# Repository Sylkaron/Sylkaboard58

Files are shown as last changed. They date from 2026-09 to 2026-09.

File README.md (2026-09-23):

# Sylkaboard58



A split ortholinear keyboard with 58 keys and two encoders for a first step in my ergonomic journey

## Table des matières
- [Overview](#-overview)
- [BOM](#️-bill-of-materials)
- [Assemblage](#-assemblage)
- [Firmware](#-firmware)
- [Layout](#-keyboard-layout)
- [Licence](#-licence)

## Overview

## BOM
 ### Keyboard

 ### Tools

## Firmware
Powered by QMK

### Requirements
- [QMK Toolbox](https://github.com/qmk/qmk_toolbox) (to flash firmware).
- [QMK Firmware](https://github.com/qmk/qmk_firmware)

### Étapes pour flasher le firmware
1. Téléchargez ou clonez le dépôt QMK :
   ```bash
   git clone https://github.com/qmk/qmk_firmware.git

## Layout

## Licence  
This project is under **[CERN OHL v2](https://ohwr.org/cern_ohl)** 
This documentation is under **[CC BY-SA 4.0](https://creativecommons.org/licenses/by-sa/4.0/)**.

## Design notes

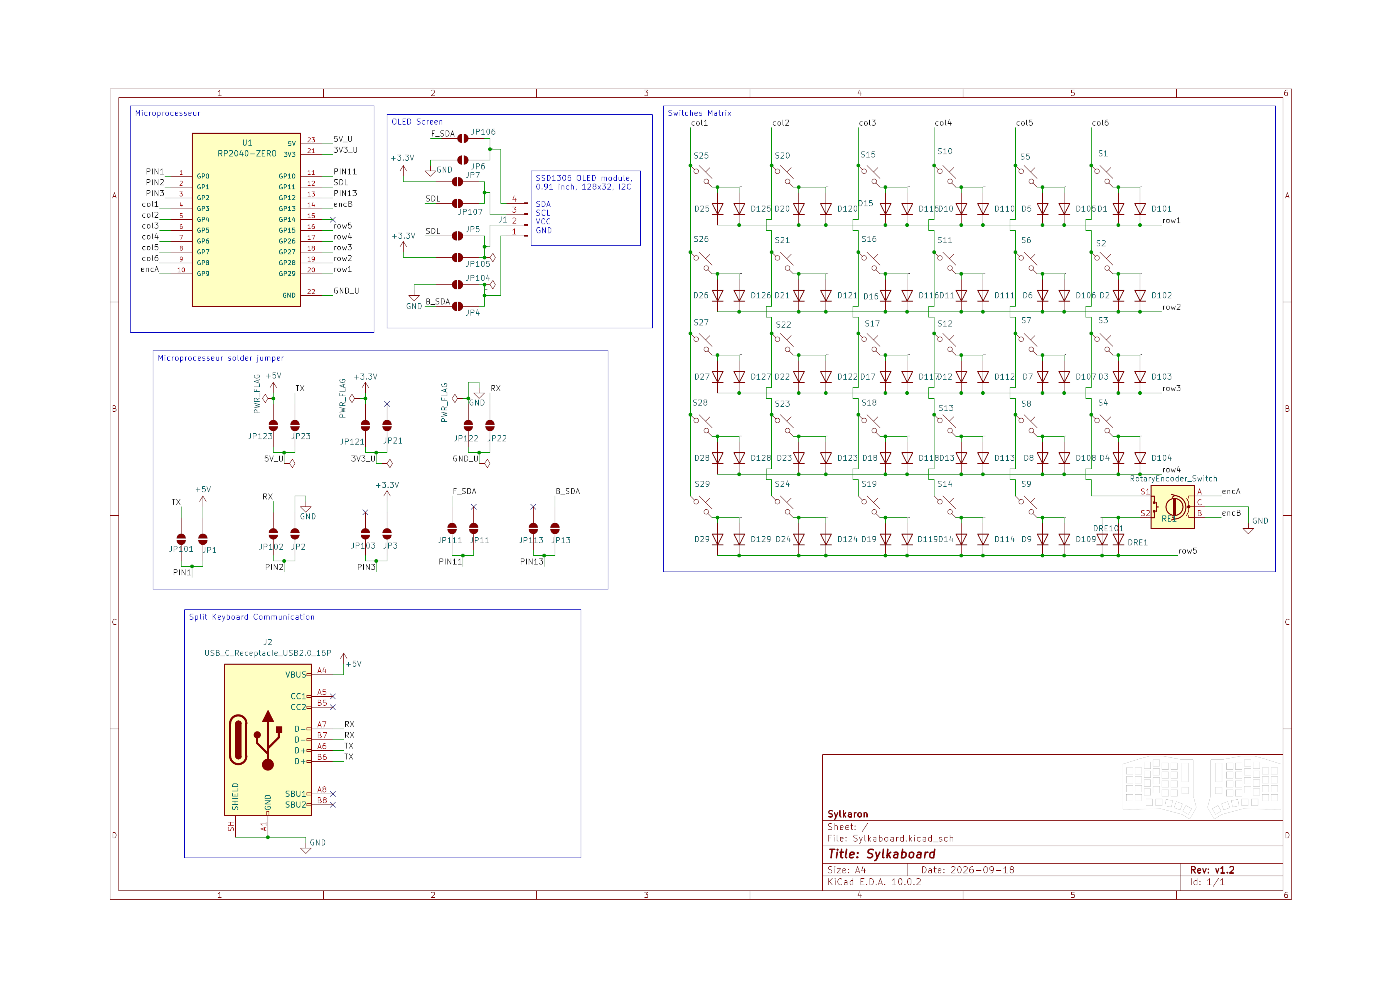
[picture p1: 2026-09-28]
Fabrications/SVG/schematic.png

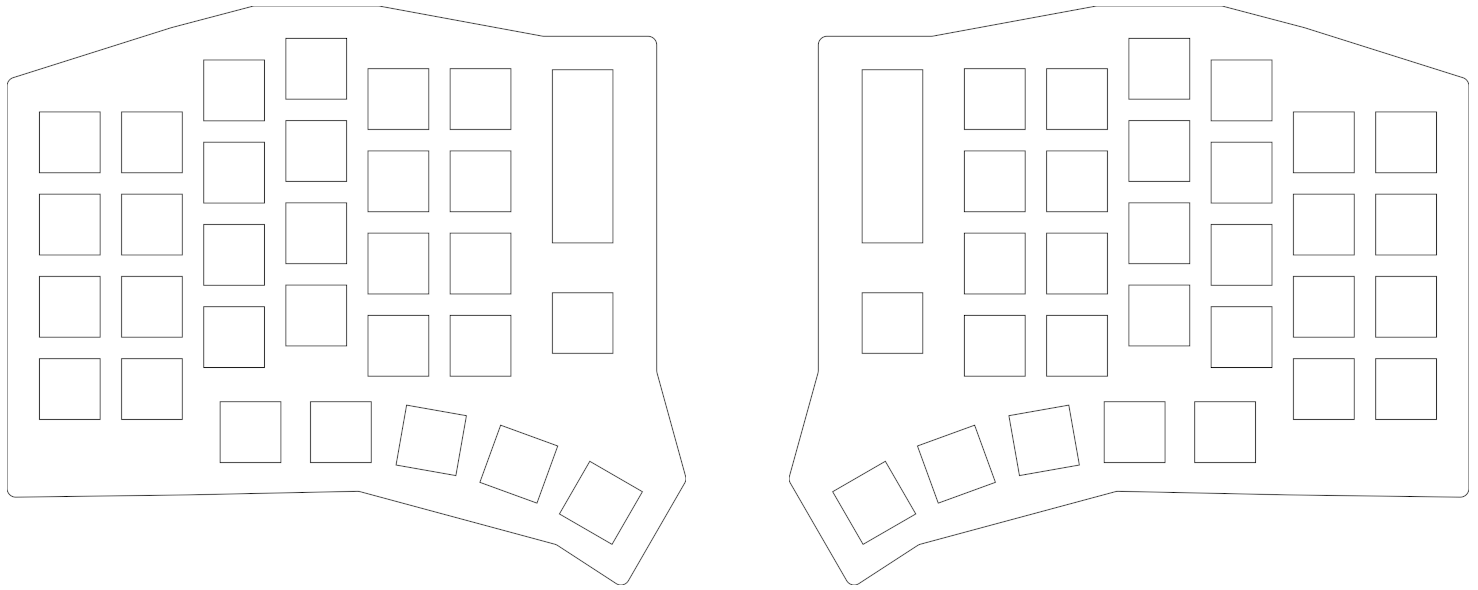
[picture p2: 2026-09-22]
Layout__definition/keyboard.png

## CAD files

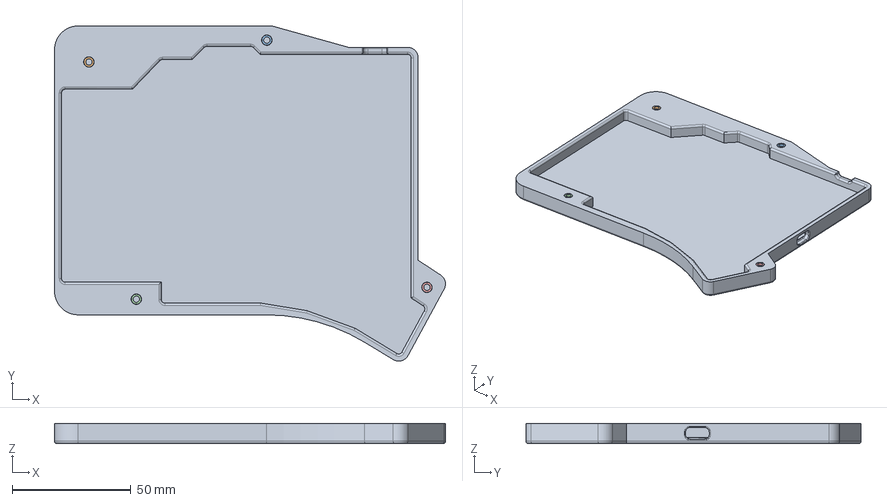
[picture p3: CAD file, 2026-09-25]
Fabrications/Case/Base_plate.FCstd
164.8 x 141.3 x 8.50 mm
Corps
M3x5.74-Insérer009
M3x5.74-Insérer
M3x5.74-Insérer012
M3x5.74-Insérer011

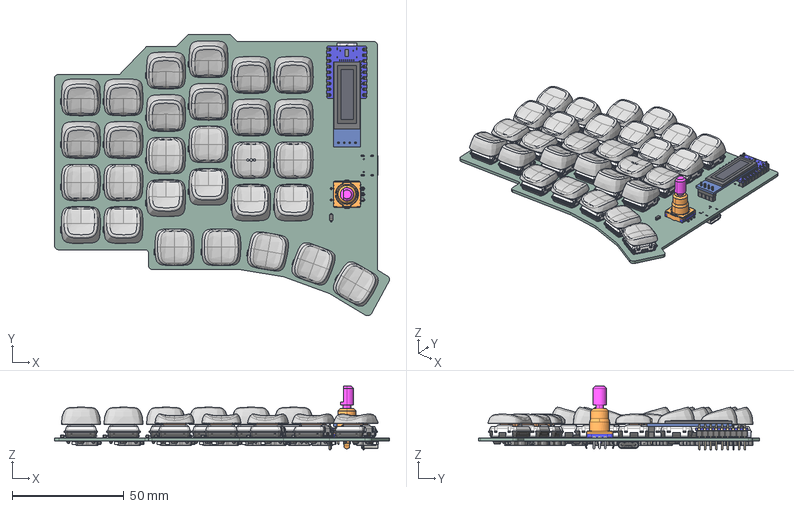
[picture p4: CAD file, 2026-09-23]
Fabrications/Case/STEP/pcb_components.step
149.6 x 125.6 x 28.5 mm
SW_Hotswap_Kailh_Choc_v1 x 29
SW_Kailh_Choc_V1_cp x 29
[Choc] Saddle Tilted v22 x 18
[Choc] Saddle v10 x 10
D_SOD-123 x 60
PinHeader_1x04_P254mm_Vertical
OLED_0.91in_128x32_SSD1306_I2C
USB_C_Receptacle_16P_TopMnt_Horizontal_GCT_USB4105-xx-A
[Choc] Saddle Homing v5
RP2040-ZERO
PinHeader_1x09_P254mm_Vertical x 2
Sylkaboard_PCB

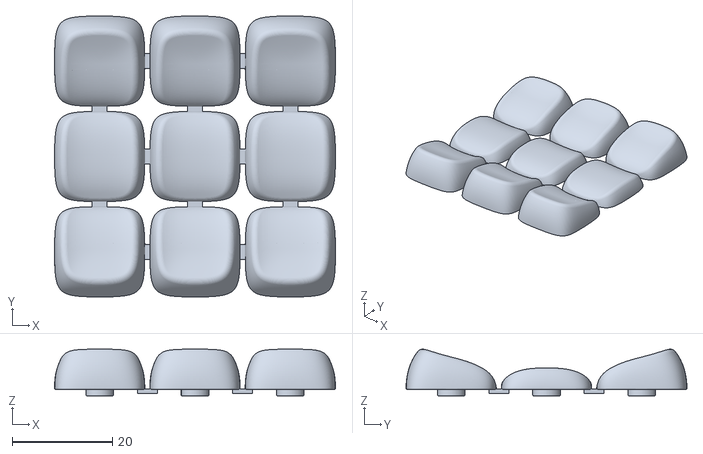
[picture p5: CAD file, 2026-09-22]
Fabrications/keycaps/8xMX_Stem_MX_Size_Saddle_Part_1.stl
56.0 x 56.0 x 9.34

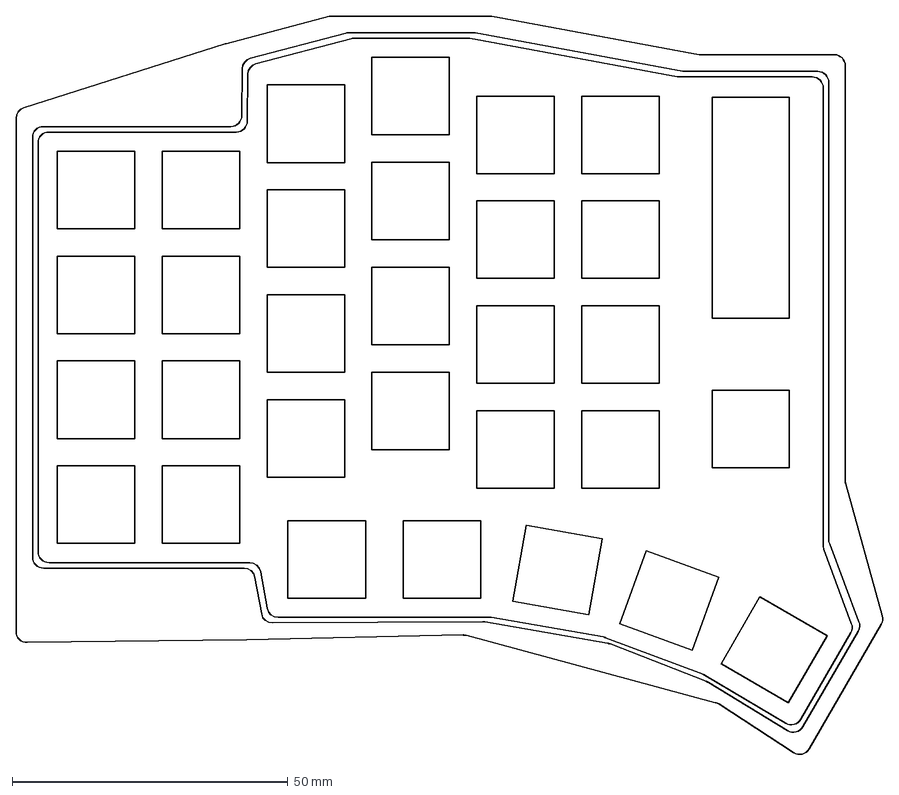
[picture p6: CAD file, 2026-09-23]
Layout__definition/all_keyb.dxf
157.1 x 133.8 mm

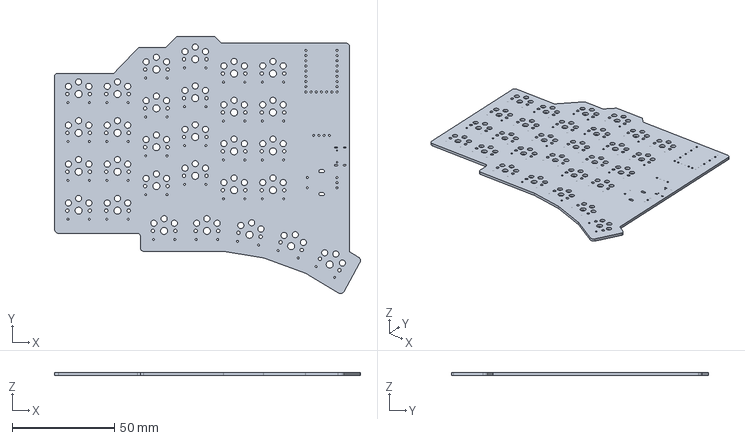
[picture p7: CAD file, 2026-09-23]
Fabrications/Case/STEP/pcb.step
149.6 x 125.6 x 1.51 mm

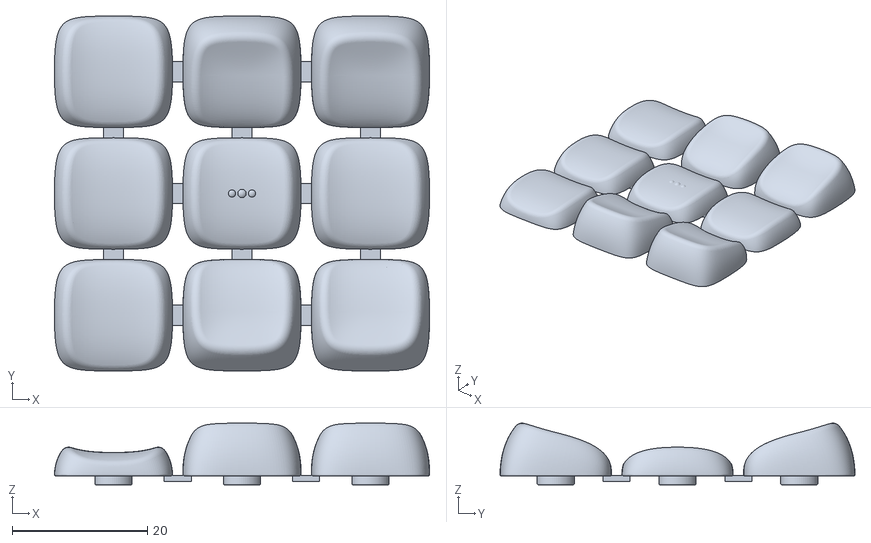
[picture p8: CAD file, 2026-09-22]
Fabrications/keycaps/4xMX_Stem_Choc_Size_Saddle_Part_2.stl
55.5 x 52.5 x 9.14

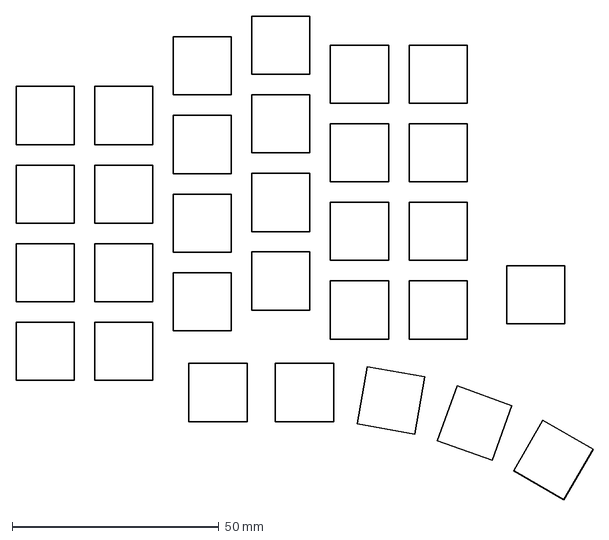
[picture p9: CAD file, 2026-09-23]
Layout__definition/switch_holes.dxf
139.5 x 116.9 mm

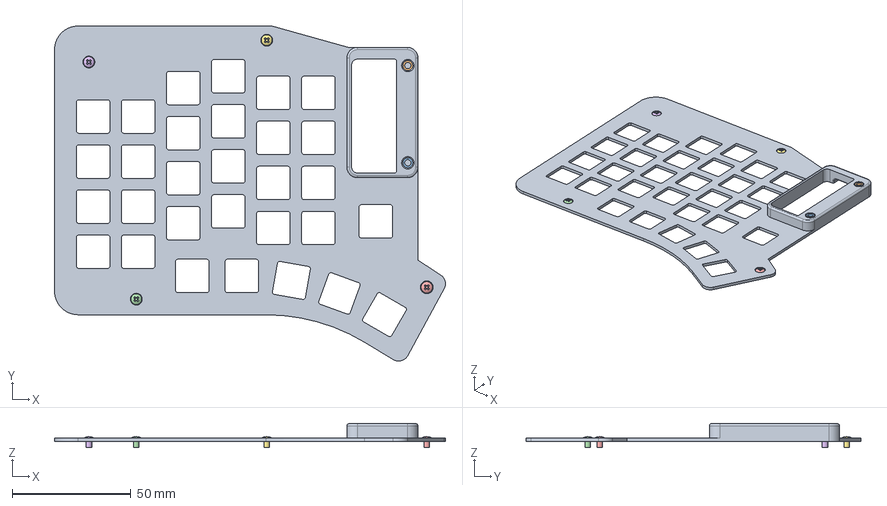
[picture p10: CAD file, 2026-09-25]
Fabrications/Case/Upper_plate.FCStd
164.9 x 141.3 x 10.3 mm
Corps
M3x5.74-Insérer
M3x5.74-Insérer027
#3x1/8in-Vis
#3x1/8in-Vis127
#3x1/8in-Vis128
#3x1/8in-Vis129

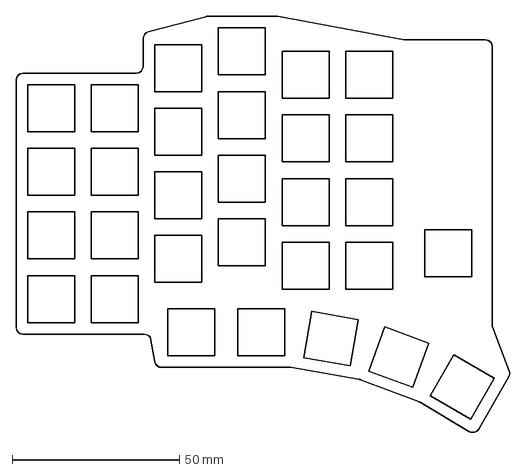
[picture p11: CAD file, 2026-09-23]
Layout__definition/pcb.dxf
147.6 x 124.4 mm

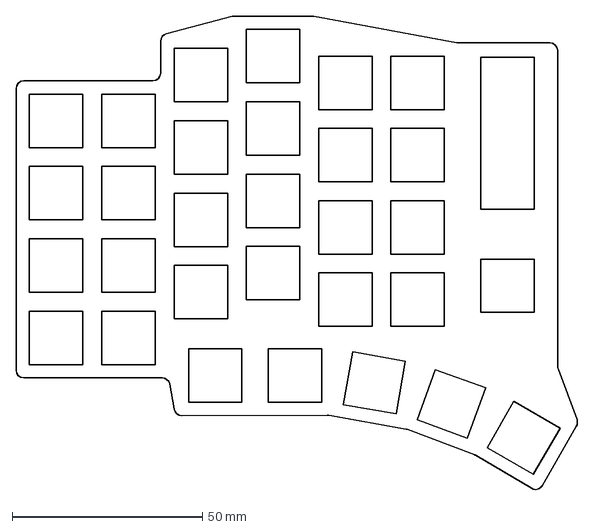
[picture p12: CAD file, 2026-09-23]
Layout__definition/compact_plate.dxf
147.6 x 124.4 mm

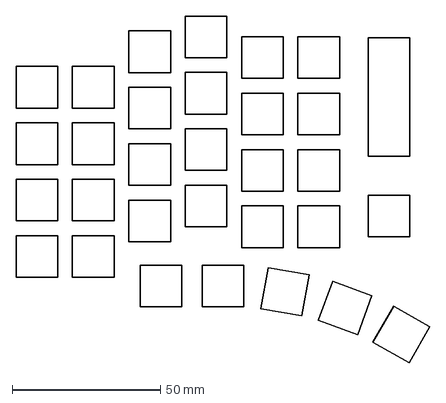
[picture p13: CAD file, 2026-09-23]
Layout__definition/holes.dxf
139.5 x 116.9 mm

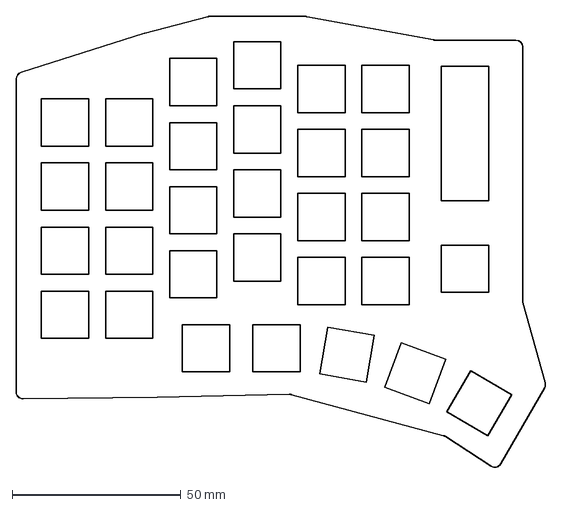
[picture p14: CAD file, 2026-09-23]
Layout__definition/ucase.dxf
157.1 x 133.8 mm

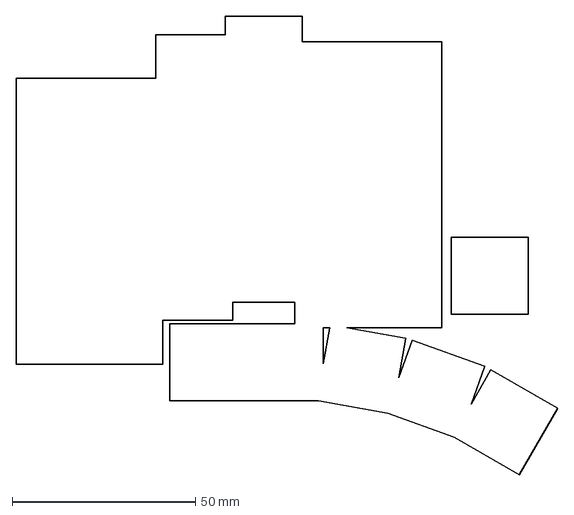
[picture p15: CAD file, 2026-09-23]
Layout__definition/raw.dxf
147.7 x 125.1 mm

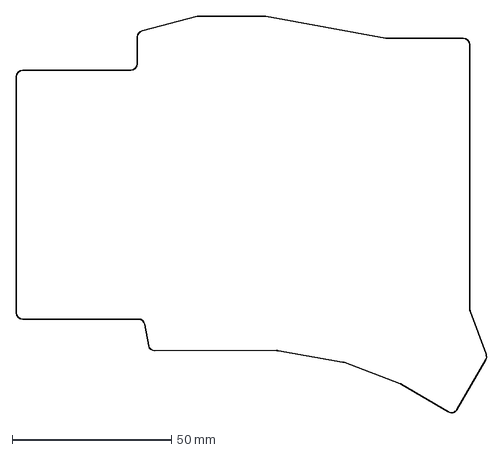
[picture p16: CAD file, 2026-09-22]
Layout__definition/lboard.dxf
147.6 x 124.4 mm

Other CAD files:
Fabrications/Case/Assemblage.FCStd
Fabrications/Case/Base.FCStd
Layout__definition/bcase.dxf
Layout__definition/screen_hole.dxf
Fabrications/Case/PCB.FCStd
Layout__definition/plboard.dxf
Layout__definition/screen_padding.dxf
Layout__definition/screen_support.dxf

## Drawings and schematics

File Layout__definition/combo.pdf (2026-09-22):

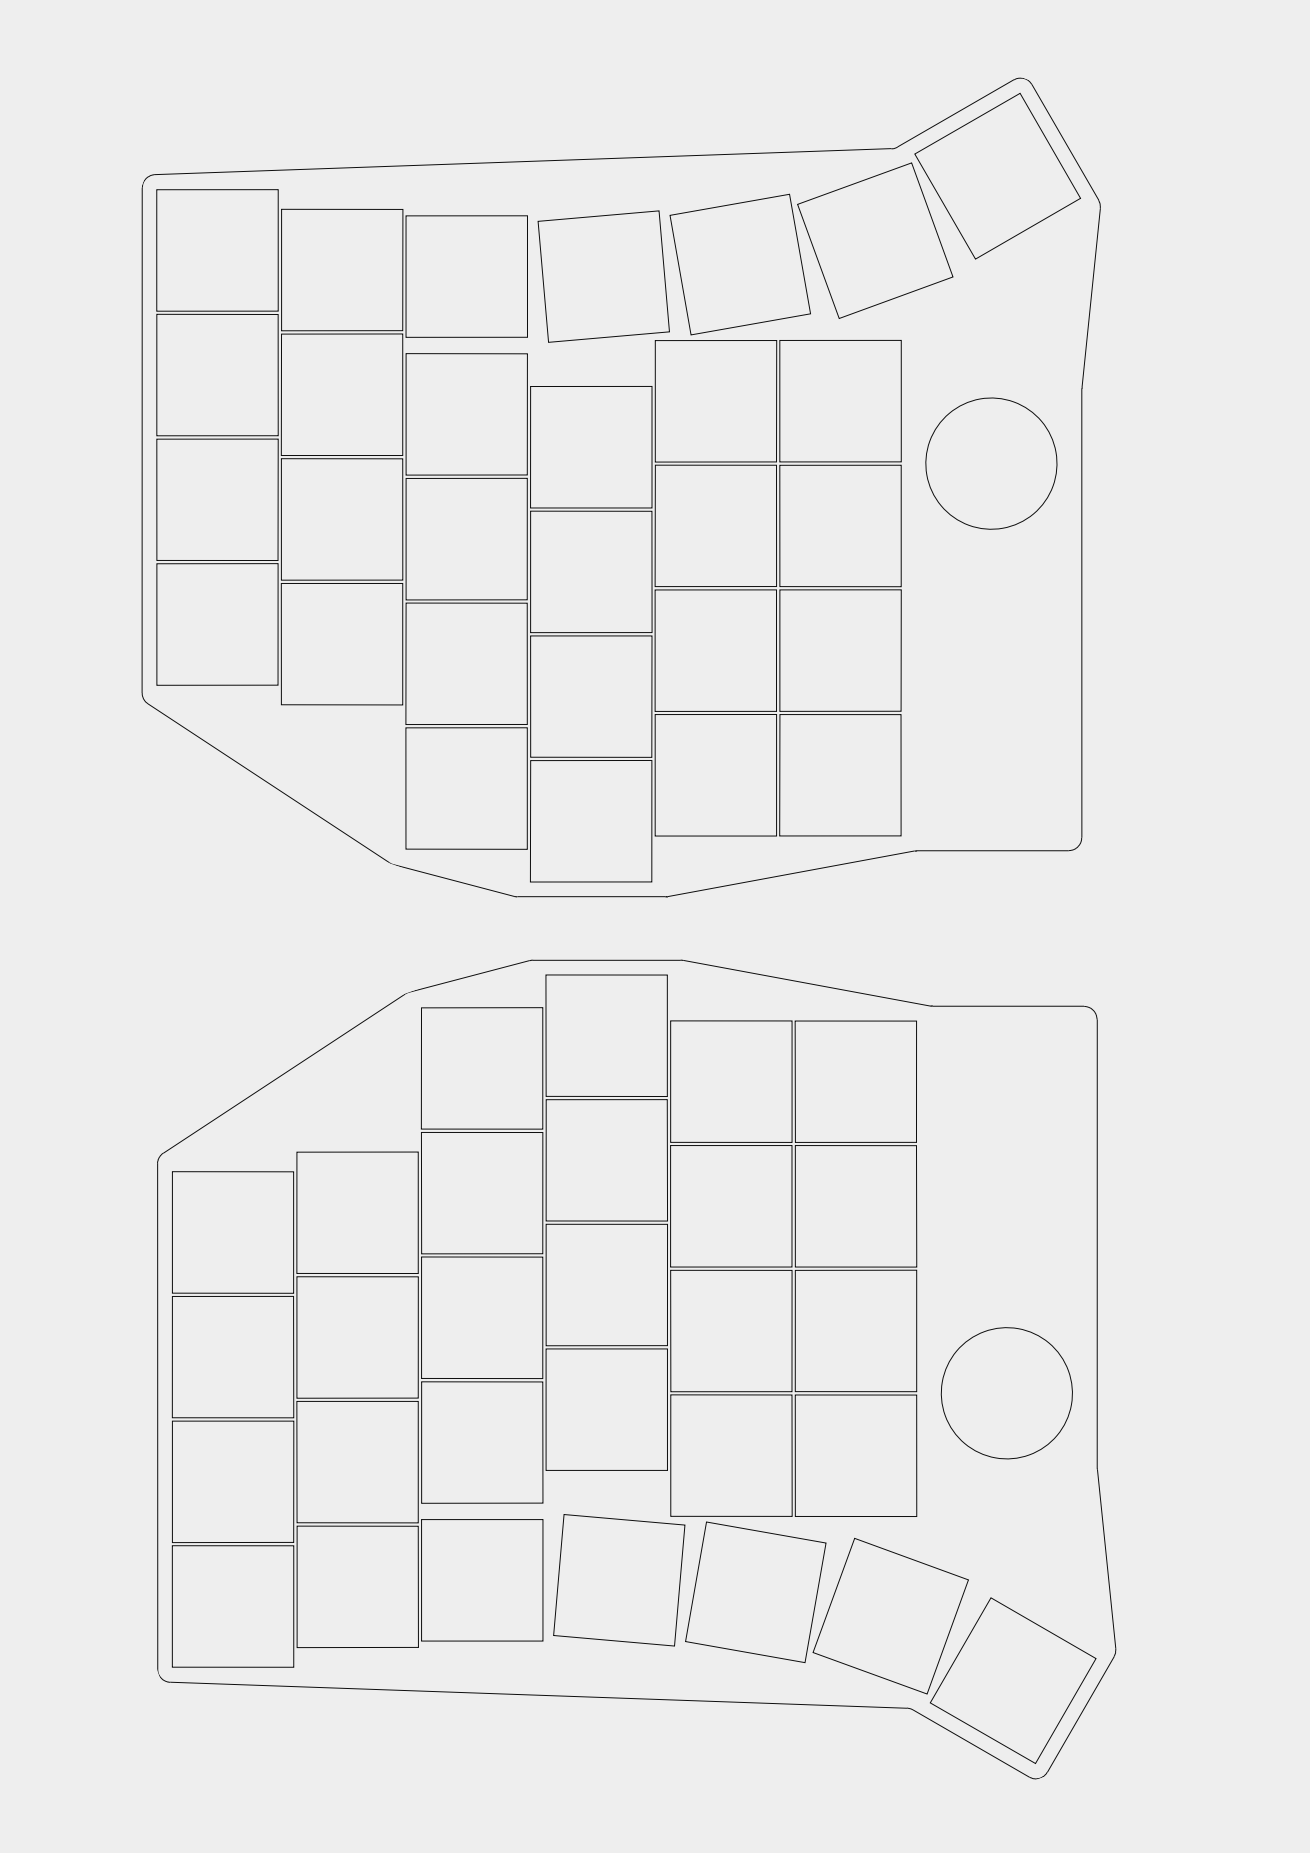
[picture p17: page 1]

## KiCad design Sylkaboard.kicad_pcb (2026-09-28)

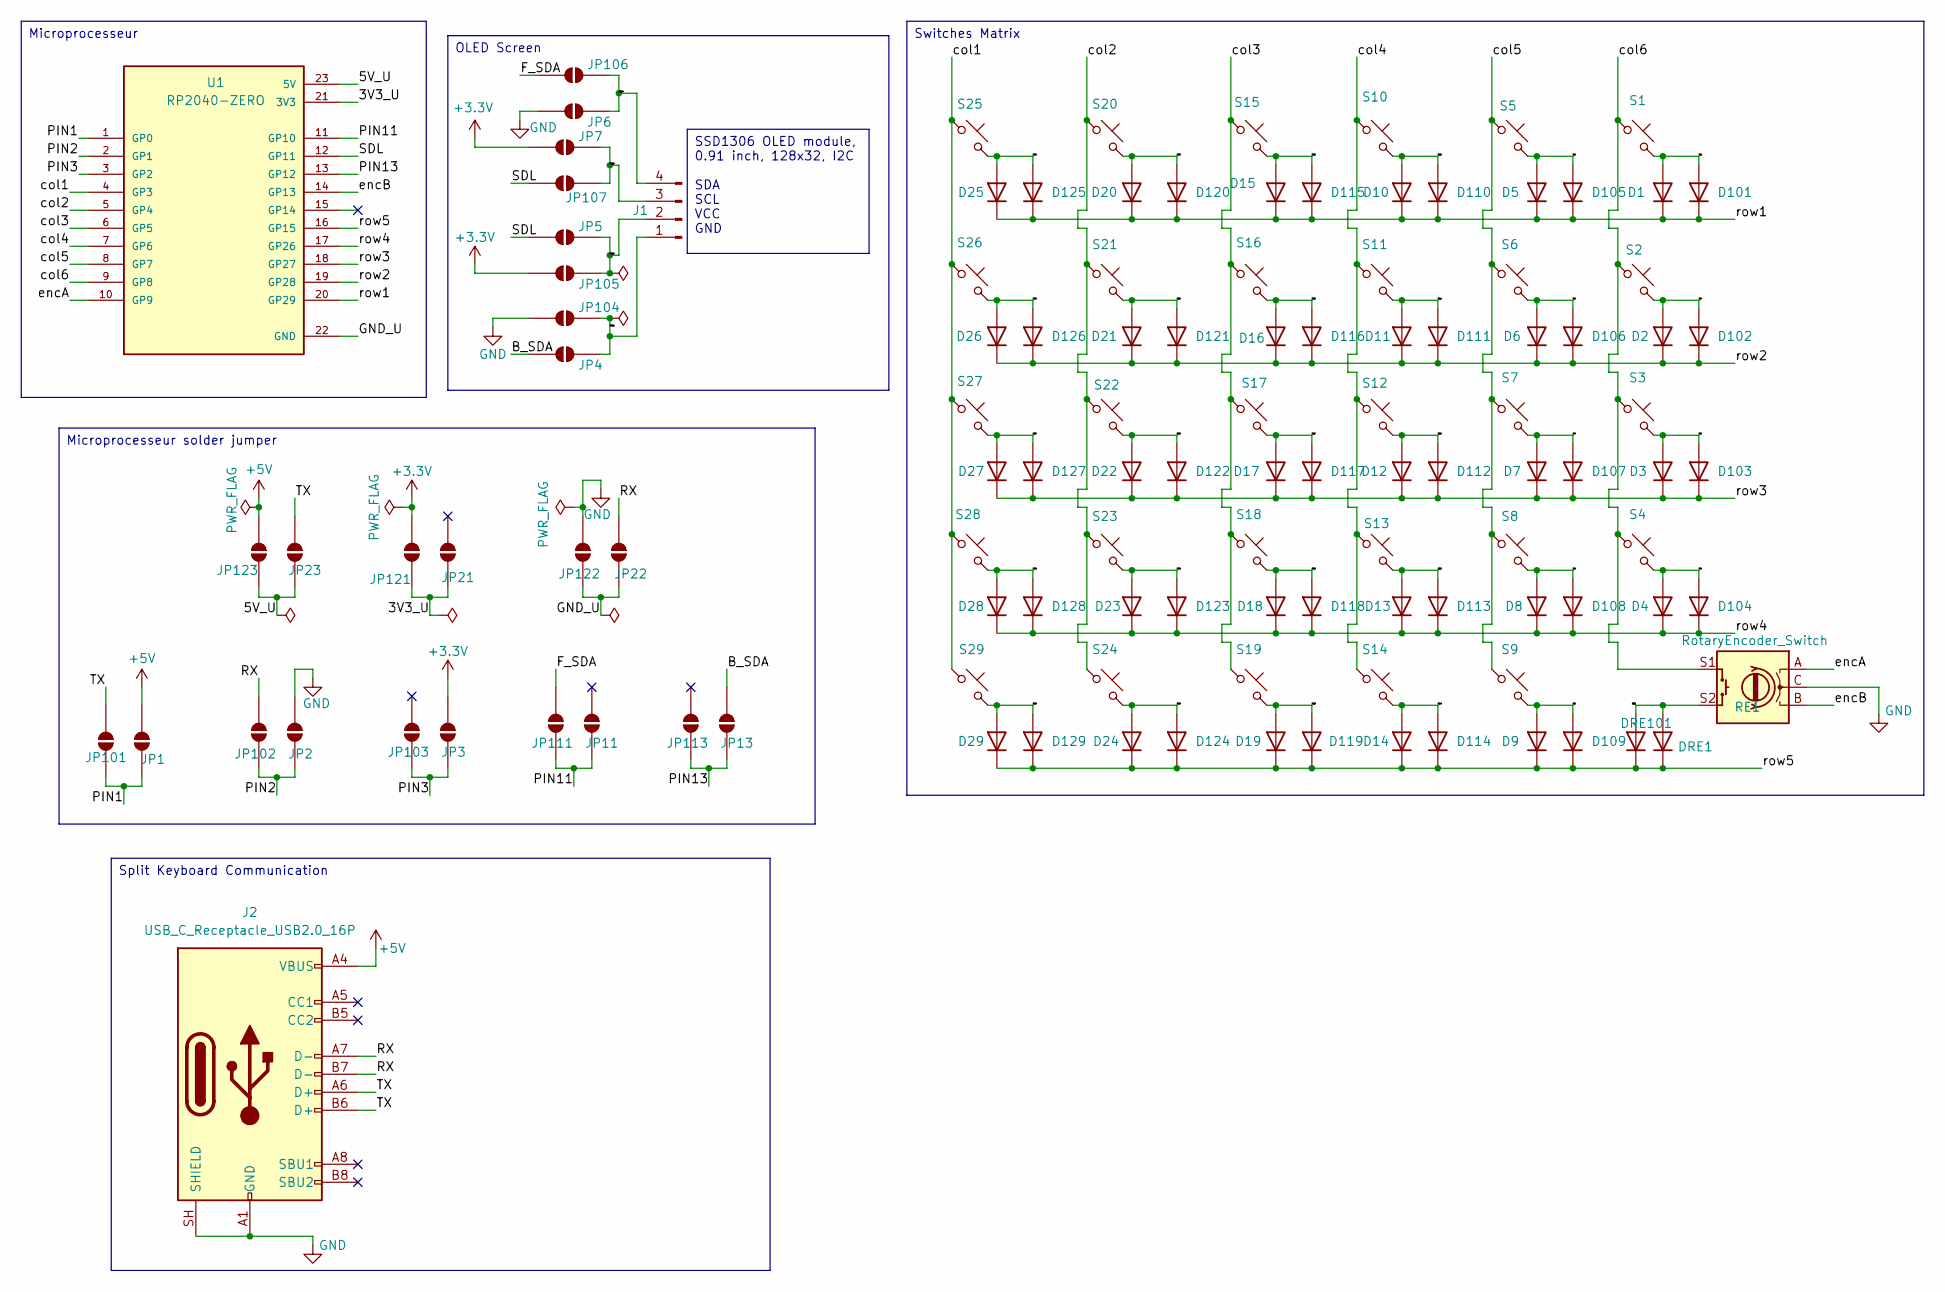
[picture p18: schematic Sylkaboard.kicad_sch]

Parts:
D1, D2, D3, D4, D5, D6, D7, D8, D9, D10, D11, D12, D13, D14, D15, D16, D17, D18, D19, D20, D21, D22, D23, D24, D25, D26, D27, D28, D29, D101, D102, D103, D104, D105, D106, D107, D108, D109, D110, D111, D112, D113, D114, D115, D116, D117, D118, D119, D120, D121, D122, D123, D124, D125, D126, D127, D128, D129: 1N4148W; D_SOD-123
DRE1, DRE101: 1N4148W; D_SOD-123
J1: Conn_01x04_Pin; PinHeader_1x04_P2.54mm_Vertical
J2: USB_C_Receptacle_USB2.0_16P; USB_C_Receptacle_G-Switch_GT-USB-7010ASV_REVERSIBLE
JP1, JP2, JP3, JP4, JP5, JP6, JP7, JP11, JP13, JP21, JP22, JP23, JP101, JP102, JP103, JP104, JP105, JP106, JP107, JP111, JP113, JP121, JP122, JP123: SolderJumper_2_Open; SolderJumper-2_P1.3mm_Open_TrianglePad1.0x1.5mm
RE1: RotaryEncoder_Switch; RotaryEncoder_Alps_EC11E-Switch_Vertical_H20mm
S1, S2, S3, S4, S5, S6, S7, S8, S9, S10, S11, S12, S13, S14, S15, S16, S17, S18, S19, S20, S21, S22, S23, S24, S25, S26, S27, S28, S29: SW_Push_45deg; Kailh_socket_PG1350_reversible
U1: RP2040-ZERO; MODULE_RP2040-ZERO; PARTREV NA

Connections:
+3.3V: JP3.2 (B), JP7.2 (B), JP105.2 (B), JP121.2 (B)
+5V: J2.A4 (VBUS), J2.A9 (VBUS), J2.B4 (VBUS), J2.B9 (VBUS), JP1.2 (B), JP123.2 (B)
/3V3_U: JP21.1 (A_1), JP121.1 (A), U1.21 (3V3)
/5V_U: JP23.1 (A), JP123.1 (A), U1.23 (5V)
/B_SDA: JP4.2 (B), JP13.2 (B)
/F_SDA: JP106.2 (B), JP111.2 (B)
/GND_U: JP22.1 (A), JP122.1 (A), U1.22 (GND)
/OLED1: J1.1, JP4.1 (A), JP104.1 (A)
/OLED2: J1.2, JP5.1 (A), JP105.1 (A)
/OLED3: J1.3, JP7.1 (A), JP107.1 (A)
/OLED4: J1.4, JP6.1 (A), JP106.1 (A)
/PIN1: JP1.1 (A), JP101.1 (A), U1.1 (GP0)
/PIN2: JP2.1 (A), JP102.1 (A), U1.2 (GP1)
/PIN3: JP3.1 (A), JP103.1 (A_1), U1.3 (GP2)
/PIN11: JP11.1 (A_1), JP111.1 (A), U1.11 (GP10)
/PIN13: JP13.1 (A), JP113.1 (A_1), U1.13 (GP12)
/RED1: DRE1.2 (A), DRE101.2 (A), RE1.S2
/RX: J2.A7 (D-), J2.B7 (D-), JP22.2 (B), JP102.2 (B)
/SD1: D1.2 (A), D101.2 (A), S1.2
/SD2: D2.2 (A), D102.2 (A), S2.2
/SD3: D3.2 (A), D103.2 (A), S3.2
/SD4: D4.2 (A), D104.2 (A), S4.2
/SD5: D5.2 (A), D105.2 (A), S5.2
/SD6: D6.2 (A), D106.2 (A), S6.2
/SD7: D7.2 (A), D107.2 (A), S7.2
/SD8: D8.2 (A), D108.2 (A), S8.2
/SD9: D9.2 (A), D109.2 (A), S9.2
/SD10: D10.2 (A), D110.2 (A), S10.2
/SD11: D11.2 (A), D111.2 (A), S11.2
/SD12: D12.2 (A), D112.2 (A), S12.2
/SD13: D13.2 (A), D113.2 (A), S13.2
/SD14: D14.2 (A), D114.2 (A), S14.2
/SD15: D15.2 (A), D115.2 (A), S15.2
/SD16: D16.2 (A), D116.2 (A), S16.2
/SD17: D17.2 (A), D117.2 (A), S17.2
/SD18: D18.2 (A), D118.2 (A), S18.2
/SD19: D19.2 (A), D119.2 (A), S19.2
/SD20: D20.2 (A), D120.2 (A), S20.2
/SD21: D21.2 (A), D121.2 (A), S21.2
/SD22: D22.2 (A), D122.2 (A), S22.2
/SD23: D23.2 (A), D123.2 (A), S23.2
/SD24: D24.2 (A), D124.2 (A), S24.2
/SD25: D25.2 (A), D125.2 (A), S25.2
/SD26: D26.2 (A), D126.2 (A), S26.2
/SD27: D27.2 (A), D127.2 (A), S27.2
/SD28: D28.2 (A), D128.2 (A), S28.2
/SD29: D29.2 (A), D129.2 (A), S29.2
/SDL: JP5.2 (B), JP107.2 (B), U1.12 (GP11)
/TX: J2.A6 (D+), J2.B6 (D+), JP23.2 (B), JP101.2 (B)
/col1: S25.1, S26.1, S27.1, S28.1, S29.1, U1.4 (GP3)
/col2: S20.1, S21.1, S22.1, S23.1, S24.1, U1.5 (GP4)
/col3: S15.1, S16.1, S17.1, S18.1, S19.1, U1.6 (GP5)
/col4: S10.1, S11.1, S12.1, S13.1, S14.1, U1.7 (GP6)
/col5: S5.1, S6.1, S7.1, S8.1, S9.1, U1.8 (GP7)
/col6: RE1.S1, S1.1, S2.1, S3.1, S4.1, U1.9 (GP8)
/encA: RE1.A, U1.10 (GP9)
/encB: RE1.B, U1.14 (GP13)
/row1: D1.1 (K), D5.1 (K), D10.1 (K), D15.1 (K), D20.1 (K), D25.1 (K), D101.1 (K), D105.1 (K), D110.1 (K), D115.1 (K), D120.1 (K), D125.1 (K), U1.20 (GP29)
/row2: D2.1 (K), D6.1 (K), D11.1 (K), D16.1 (K), D21.1 (K), D26.1 (K), D102.1 (K), D106.1 (K), D111.1 (K), D116.1 (K), D121.1 (K), D126.1 (K), U1.19 (GP28)
/row3: D3.1 (K), D7.1 (K), D12.1 (K), D17.1 (K), D22.1 (K), D27.1 (K), D103.1 (K), D107.1 (K), D112.1 (K), D117.1 (K), D122.1 (K), D127.1 (K), U1.18 (GP27)
/row4: D4.1 (K), D8.1 (K), D13.1 (K), D18.1 (K), D23.1 (K), D28.1 (K), D104.1 (K), D108.1 (K), D113.1 (K), D118.1 (K), D123.1 (K), D128.1 (K), U1.17 (GP26)
/row5: D9.1 (K), D14.1 (K), D19.1 (K), D24.1 (K), D29.1 (K), D109.1 (K), D114.1 (K), D119.1 (K), D124.1 (K), D129.1 (K), DRE1.1 (K), DRE101.1 (K), U1.16 (GP15)
GND: J2.A1 (GND), J2.A12 (GND), J2.B1 (GND), J2.B12 (GND), J2.SH (SHIELD), JP2.2 (B), JP6.2 (B), JP104.2 (B), JP122.2 (B), RE1.C

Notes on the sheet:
Split Keyboard Communication
Microprocesseur solder jumper
Microprocesseur
SSD1306 OLED module, 0.91 inch, 128x32, I2C SDA SCL VCC GND
OLED Screen
Switches Matrix

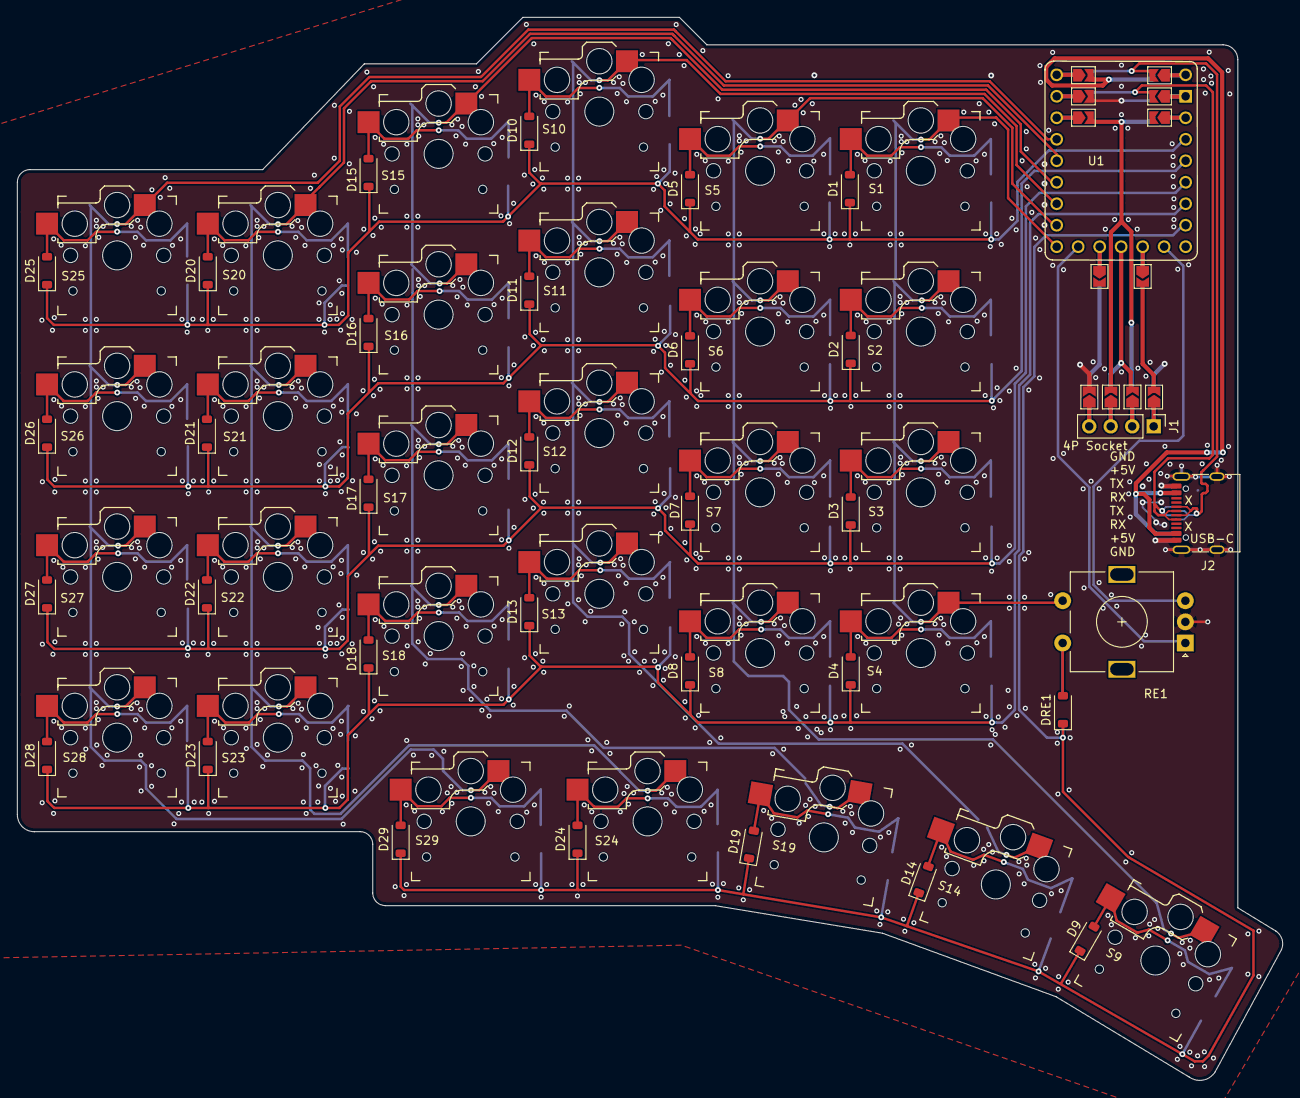
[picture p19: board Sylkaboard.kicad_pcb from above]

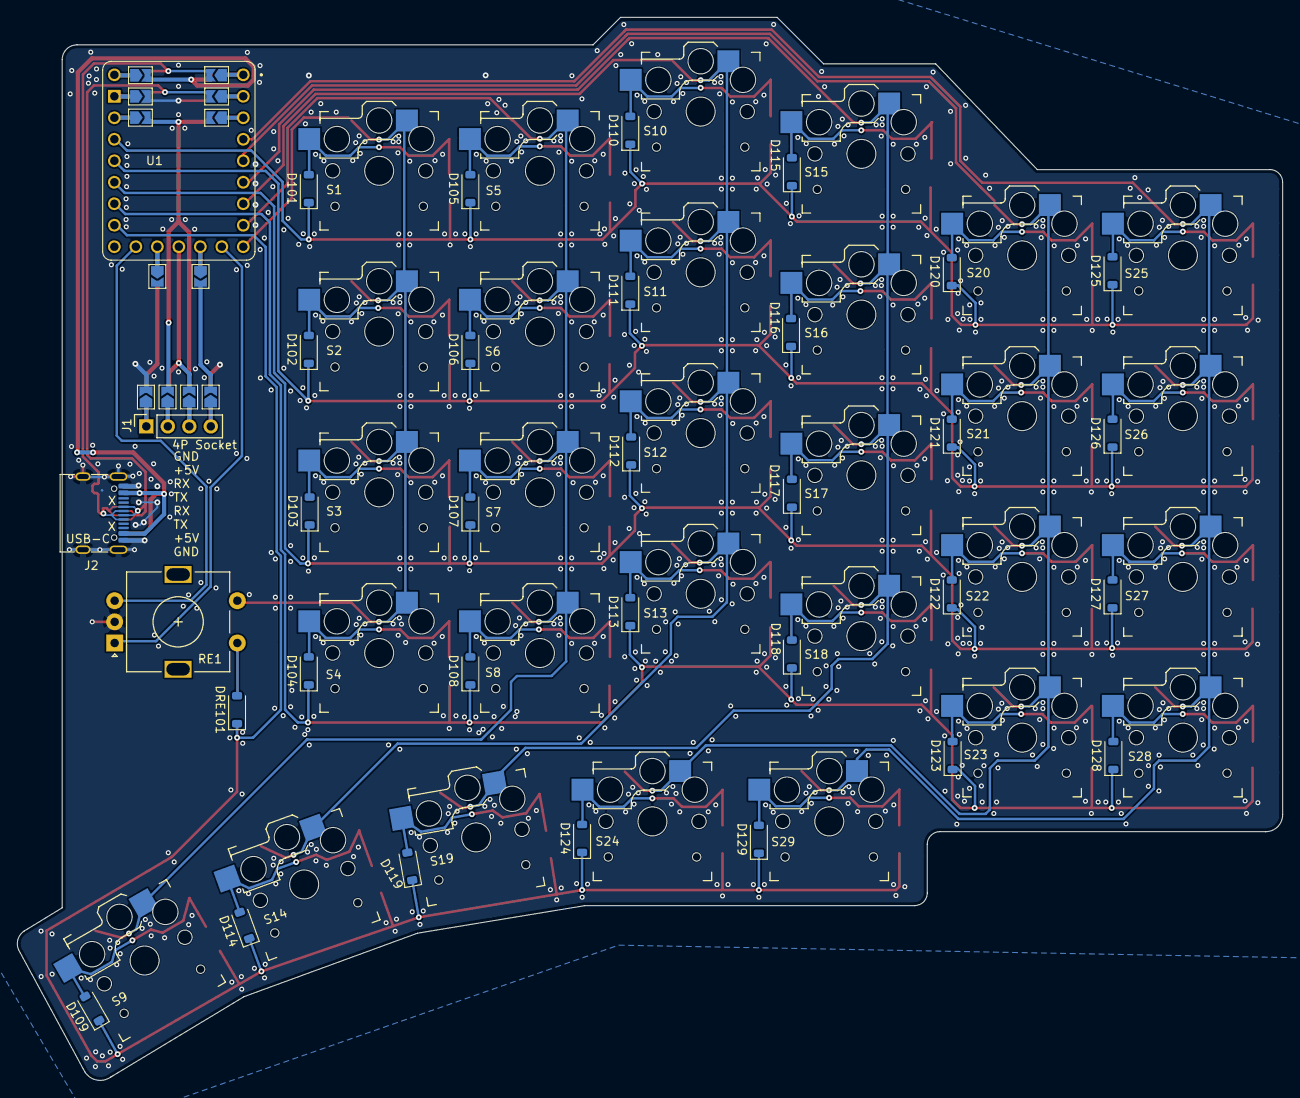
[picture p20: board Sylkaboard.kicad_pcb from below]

Board: 2 copper layers, 149.6 x 125.6 mm, 117 parts (43 on the bottom side), 63 nets.

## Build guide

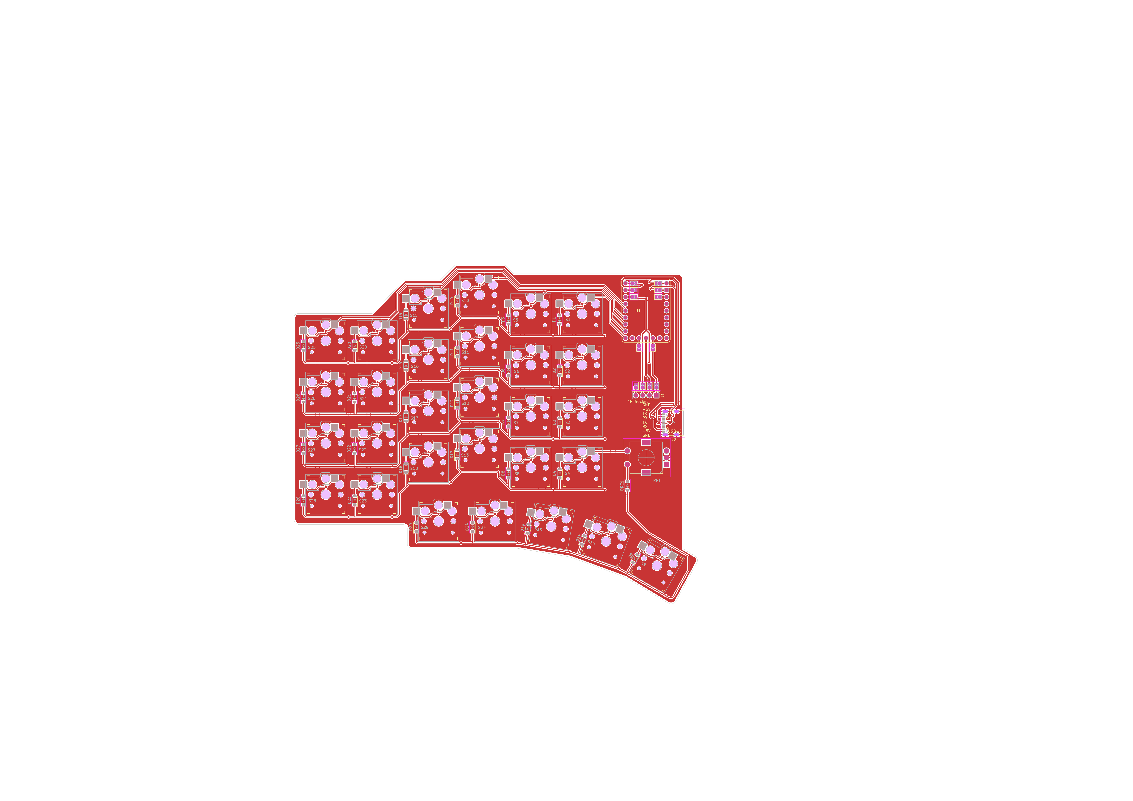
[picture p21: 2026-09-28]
Fabrications/SVG/Sylkaboard-F_Cu.png

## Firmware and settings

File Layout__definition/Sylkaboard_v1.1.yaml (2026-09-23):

meta:
  engine: 4.1.0

units:
  # Switch dimensions
  sw_supp: 14.05
  sw_side: 15
  sw_plate_space: 1.6
  sw_bts: 2
  # Plate width
  pw: 1.5
  # Rotary encoder dimensions
  ec_side: 14
  ec_r: 10
  ec_d: 2ec_r
  # Screen dimension
  sc_long: 38
  sc_large: 12
  sc_high: 6
  # Key Spacing Variables
  kx: u
  ky: u
  # Padding Variables
  px: kx + 2
  py: ky + 2

points:
  zones:
    matrix:
      # Fix placement on KiCAS Sheet
      anchor:
        shift: [100, -100]
        rotate: 20
      key:
        tags: [matrix]
        padding: ky
        spread: kx
      columns:
        outer:
          key:
            column_net: P29
        pinky:
          key:
            stagger: 0
            column_net: P28
        ring:
          key:
            stagger: 12
            column_net: P27
        middle:
          key:
            stagger: 5
            column_net: P26
        index:
          key:
            stagger: -7
            column_net: P15
        inner:
          key:
            stagger: 0
            column_net: P14
      rows:
        bottom:
           row_net: P6
        home:
          row_net: P5
        top:
          row_net: P4
        num:
          row_net: P3

    thumb:
      key:
        tags: [thumb]
        spread: 1.1kx
      anchor:
        ref: matrix_inner_bottom
        shift: [-2.8kx,-1.05ky]
      rows:
        cluster:
          row_net: P7
          rotate: 0
      columns:
        gui:
          key:
            column_net: P29
        symbol:
          key:
            column_net: P28
        layer:
          key:
            stagger: -0.1ky
            splay: -10
            column_net: P27
        space:
          key:
            stagger: -0.1ky
            splay: -10
            column_net: P26
        extra:
          key:
            stagger: -0.1ky
            splay: -10
            column_net: P15

    encoder:
      key:
        tags: [encoder]
        spread: ec_d
        width: ec_d
        column_net: P14
        row_net: P7

      anchor:
        ref: matrix_inner_bottom
        shift: [1.125px, 0.175py]
  rotate: -20


outlines:
  raw:
    - what: rectangle
      where: true
      size: [px, py]

  # Screen case support
  screen_hole:
    - what: rectangle
      where:
        ref: matrix_inner_top
        shift: [1.125px, 0.275py]
      size: [sc_large + 2, sc_long + 2]
  screen_padding:
    - what: rectangle
      where:
        ref: matrix_inner_top
        shift: [1.125px, 0.275py]
      size: [sc_large + 4, sc_long + 4]
  screen_support:
    - name: screen_padding
    - operation: subtract
      name: screen_hole

  switch_holes:
    - what: rectangle
      where: [matrix, thumb, thumb_bonus]
      size: [sw_supp, sw_supp]
    - what: rectangle
      where: [encoder]
      size: [ec_side, ec_side]
    # - what: circle
    #   where: [encoder]
    #   radius: ec_r

  holes:
    - name: switch_holes
    - operation: stack
      name: screen_hole

  # Board dimensions
  lboard:
    - what: polygon
      operation: stack
      points:
        - ref: thumb_extra_cluster
          shift: [0.5px, -0.5py]
        - ref: thumb_space_cluster
          shift: [0.5px, -0.5py]
        - ref: thumb_layer_cluster
          shift: [0.5px, -0.5py]
        - ref: thumb_layer_cluster
          shift: [-0.5px, -0.5py]
        - ref: thumb_gui_cluster
          shift: [-0.5px, -0.5py]
        - ref: matrix_pinky_bottom
          shift: [0.5px, -0.5py]
        - ref: matrix_outer_bottom
          shift: [-0.5px, -0.5py]
        - ref: matrix_outer_num
          shift: [-0.5px, 0.5py]
        - ref: matrix_pinky_num
          shift: [0.4px, 0.5py]
        - ref: matrix_ring_num
          shift: [-0.5px, 0.5py]
        - ref: matrix_middle_num
          shift: [-0.5px, 0.5py]
        - ref: matrix_middle_num
          shift: [0.5px, 0.5py]
        - ref: matrix_inner_num
          shift: [0.5px, 0.5py]
        - ref: matrix_inner_num
          shift: [1.75px, 0.5py]
        - ref: matrix_inner_home
          shift: [1.75px,-0.5py-0.5ky]
        - ref: matrix_inner_home
          shift: [1.75px, -1.75py]
        - ref: thumb_extra_cluster
          shift: [0.5px, 0.5py]
      fillet: 2
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

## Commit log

2026-09-22 First commit to dont loose anything anymore
    [4xMX_Stem_Choc_Size_Saddle_Part_2.stl, 8xMX_Stem_MX_Size_Saddle_Part_1.stl, Assemblage.FCStd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]
2026-09-22 swap usb-c connector and rotary encoder
    [Sylkaboard - Copie.kicad_pcb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]
2026-09-23 rotary encoder adjustements
    [Assemblage_top.FCStd, PCB.FCStd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]
2026-09-25 inverted encoder pins (A and B) on schematic
    [Sylkaboard.kicad_pcb, Sylkaboard.kicad_sch]
2026-09-25 some sorting
    [ergogen_sylkaboard.kicad_pcb, hand_data.csv, personal_hand_data.csv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]
2026-09-25 more sorting
    [Assemblage.FCStd, Assemblage_top.FCStd, Base.FCStd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]
2026-09-25 keep sorting
    [Base_plate-Corps.step, pcb.step, pcb_components.step]
2026-09-28 rx tx of the same length
    [Sylkaboard.kicad_pcb, Sylkaboard.kicad_sch]
2026-09-28 last modification before review
    [Sylkaboard-B_Cu.gbr, Sylkaboard-B_Mask.gbr, Sylkaboard-B_Paste.gbr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]
2026-09-28 Silkscreen and references modifications
    [Sylkaboard-B_Cu.gbr, Sylkaboard-B_Mask.gbr, Sylkaboard-B_Paste.gbr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]
2026-10-28 change switch footprint to a correct dimension holes
2026-10-28 update 3D model (keys nearer to the pcb)
2026-10-29 case adaptation after first proto
2026-10-30 case final adaptations and stl exports

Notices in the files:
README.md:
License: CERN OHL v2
